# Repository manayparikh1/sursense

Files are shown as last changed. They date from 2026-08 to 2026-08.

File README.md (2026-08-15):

# SurSense

OK so I have been planning this out for years and finally its happening. A palm-sized puck that listens to you play, works out what scale you're in, and drones
along with you playing.

Point it at an instrument and with its mic it names the tonic and the scale in both Western and Indian
notation, like "C# Kafi / Dorian", then plays a tanpura drone tuned to that tonic. It's
also a chromatic tuner and a metronome that knows taal cycles like teental, with a silent
haptic mode so you can use it in an ensemble.

Every tuner tells you one note. BUT almost nothing tells you what key the whole piece is in,
and nothing I've found does it with sargam and a drone attached. So I solved that...

## Status

The detection algorithm is written and tested by me so thats done. The hardware is designed but not built yet because funding is still needed,
so right now this repo is the design plus the software that will run on it.

The self-test scores 24 out of 24 on tonic detection so it works obviously. It generates twelve synthesized
scales per mode, one for each tonic, runs them through the pipeline AND checks the answer in the same time.

## Test it

To test it all you gotta run is this:

cd sur && clang++ -std=c++17 -O2 -Wall -Wextra -o selftest sur.cpp selftest.cpp && ./selftest

THIS WILL ONLY TAKE A FEW SECONDS TRUST LOL. No hardware, no libraries, no build system. Compiles clean under
-Wall -Wextra.

## How it works

1. FFT the incoming audio and find the peaks, with parabolic interpolation so low notes
   land on the right semitone instead of smearing across two.
2. Fold those peaks into 12 pitch classes, weighted by how close each peak sits to the
   centre of a semitone. Accumulate over a few seconds.
3. Correlate against the Krumhansl-Schmuckler probe-tone profile at all 12 rotations to
   find the tonic.
4. Break major/minor ties with a second accumulator that decays more slowly. Whichever
   pitch class stays lit longest is the tonic.
5. Match what's left against the scale candidates.
6. Hold the answer with a locking state machine. Lock easily, unlock reluctantly, so the
   display isn't flickering between two guesses.

Step 4 is the bit I didn't get from a paper. C major and A minor use identical notes, so
correlation on its own can't tell them apart. What separates them is which note is being
*sustained* rather than just present which I learned after a good time of research.

THIS IS HOW I TESTED:

I wanted to check that actually mattered, so I measured it. The self-test holds the tonic
for 0.6s and everything else for 0.3s, and that difference is exactly what the sustain bias
reads. As written it scores 24/24, and turning the bias off only drops it to 23/24, because
the timing cue is still there in other ways. Equalise every note to 0.3s and it falls to
21/24 with the bias on, and 14/24 with it off. So the bias is doing real work, but it's a
seven-point difference, not the difference between working and not working. 

## What it can't do

The self-test is synthetic and I wrote both the detector and the grader, so it proves my
implementation matches my intent. It doesn't prove the thing survives a real room.

Short phrases are undecidable no matter how good the code is. Five notes can't tell Dorian
from natural minor if the note that distinguishes them never got played.

Percussion dumps energy across every bin and will drag accuracy down so yeah.

And nothing has run on hardware yet.

BUT WE WILL FIX MOSTLY ALLLLL OF THAT once the hardware arrives because I am going full-in in this project.

## Hardware

70mm puck, 22mm tall. The knurled metal bezel is the rotary encoder, so the whole ring
turns and you can set tempo by feel without looking down while you're holding an
instrument. It's the same idea as the dial on my AC unit at home.

BOM.csv is also in a sheet which was actually the original one before I made the one in the repo:
https://docs.google.com/spreadsheets/d/1nKPMvtGOhtMLgeP8bByzdkwNMy8-5KtI2vqGwreh8vg/edit?usp=sharing

Total is approx $162.75 USD across ten items, converted from Amazon.ca listings but those prices can prolly flunctuate from times because it already happened to me once which was hectic.

One ESP32-S3, not three. The build only ever needed one processor. Some of the parts only
sell in multipacks, which is why a few line items cost more than a single unit would but it will try to be used because I may need EXTRA pins because of a future plan I have.

### Pin map

One ESP32-S3-WROOM-1-N8R2, 20 GPIO out of 44. Both I2S peripherals are in use, which is the
whole reason for the S3 over an S2 or a classic ESP32: the mic has to capture while the amp
drives the drone. Strapping pins 0, 3, 45 and 46 are left alone.

SD on the amplifier runs off a GPIO instead of being hard-wired, so the amp can be muted
while detection is running. That's the main thing stopping the device from hearing its own
drone and locking onto it.

VBAT sense needs a divider. A full cell sits at 4.2V and the ADC tops out at 3.3V, so GPIO1
can't go straight to the battery. Two 100k resistors and a 100nF cap.

## Design

### Power and signal

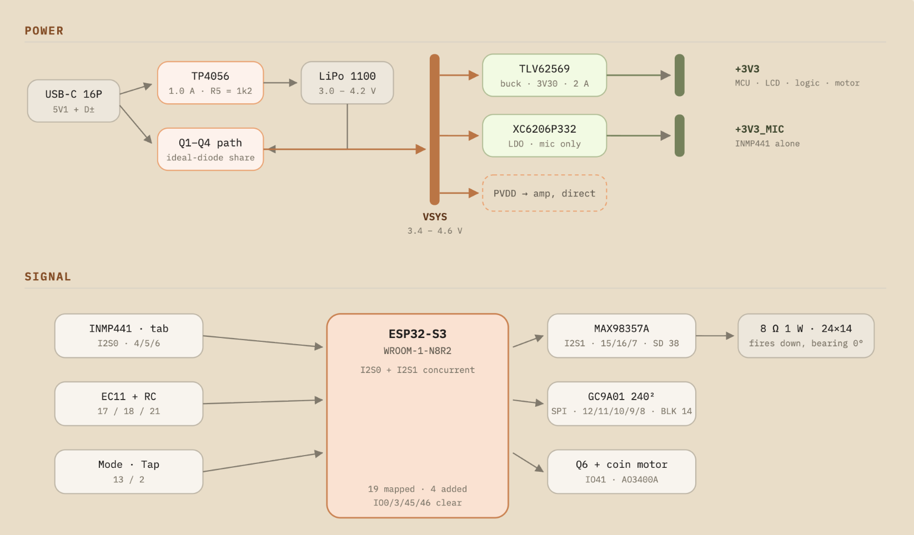
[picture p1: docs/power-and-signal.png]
Power and signal


### PCB placement

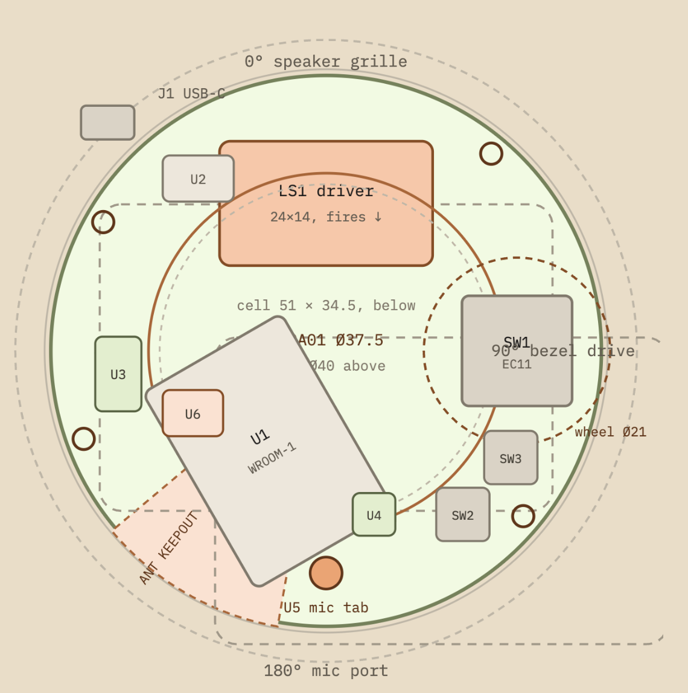
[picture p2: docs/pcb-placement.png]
PCB placement


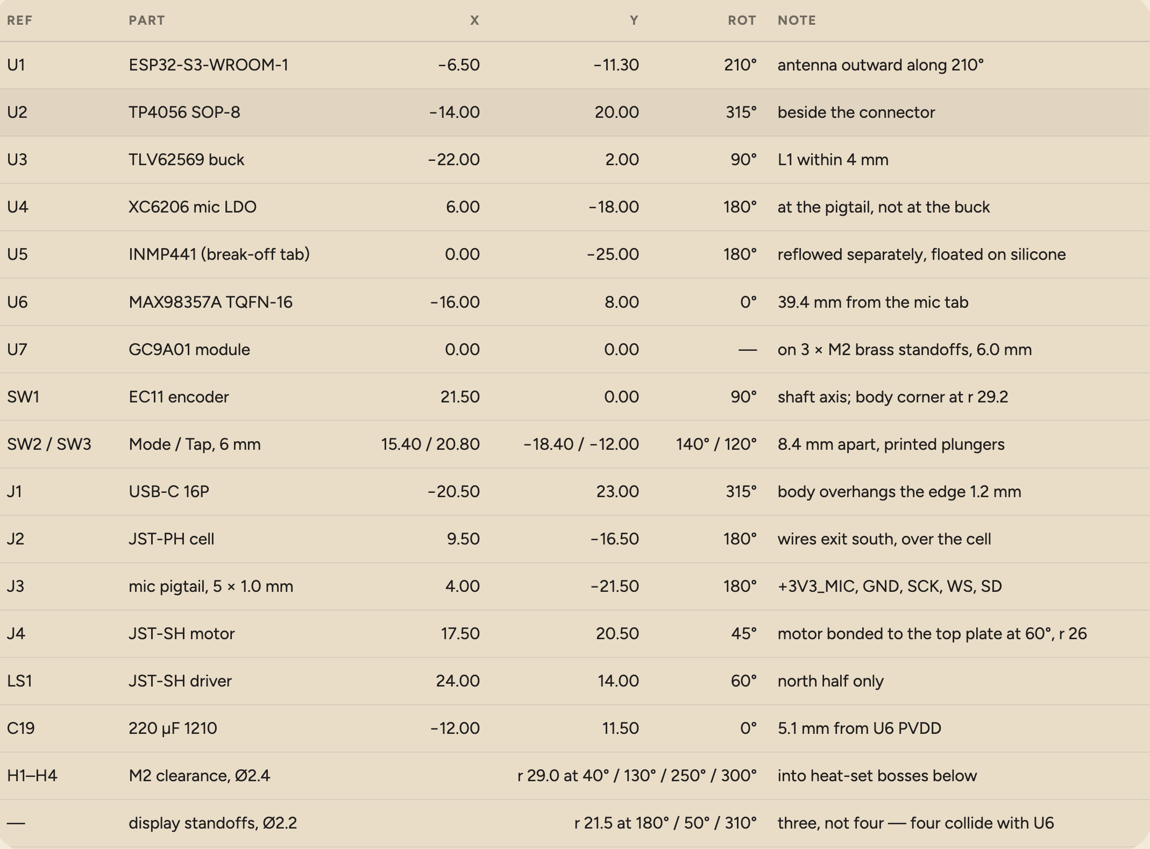
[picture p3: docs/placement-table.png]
Placement table


### Enclosure

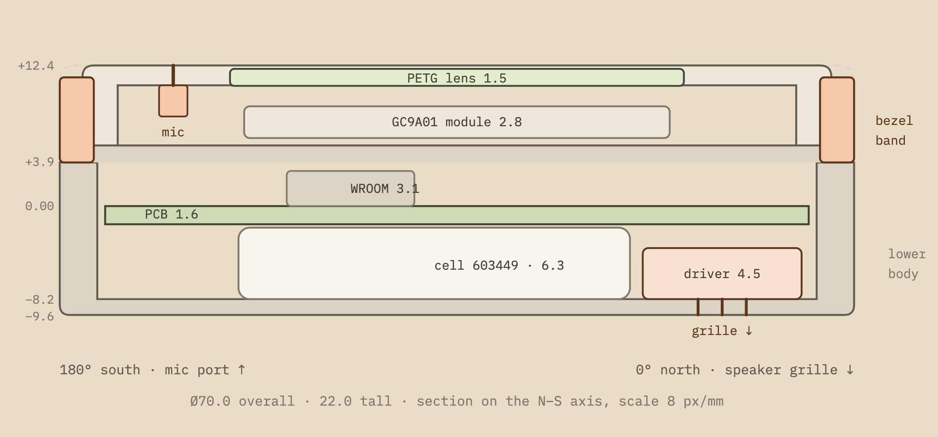
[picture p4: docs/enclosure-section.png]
Enclosure section


### Bezel coupling

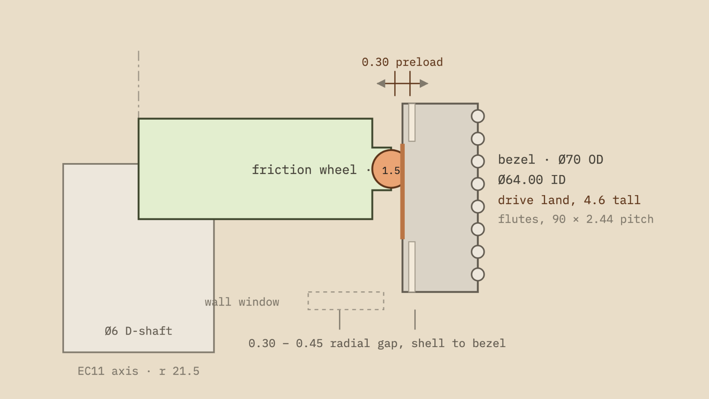
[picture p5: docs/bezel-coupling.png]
Bezel coupling


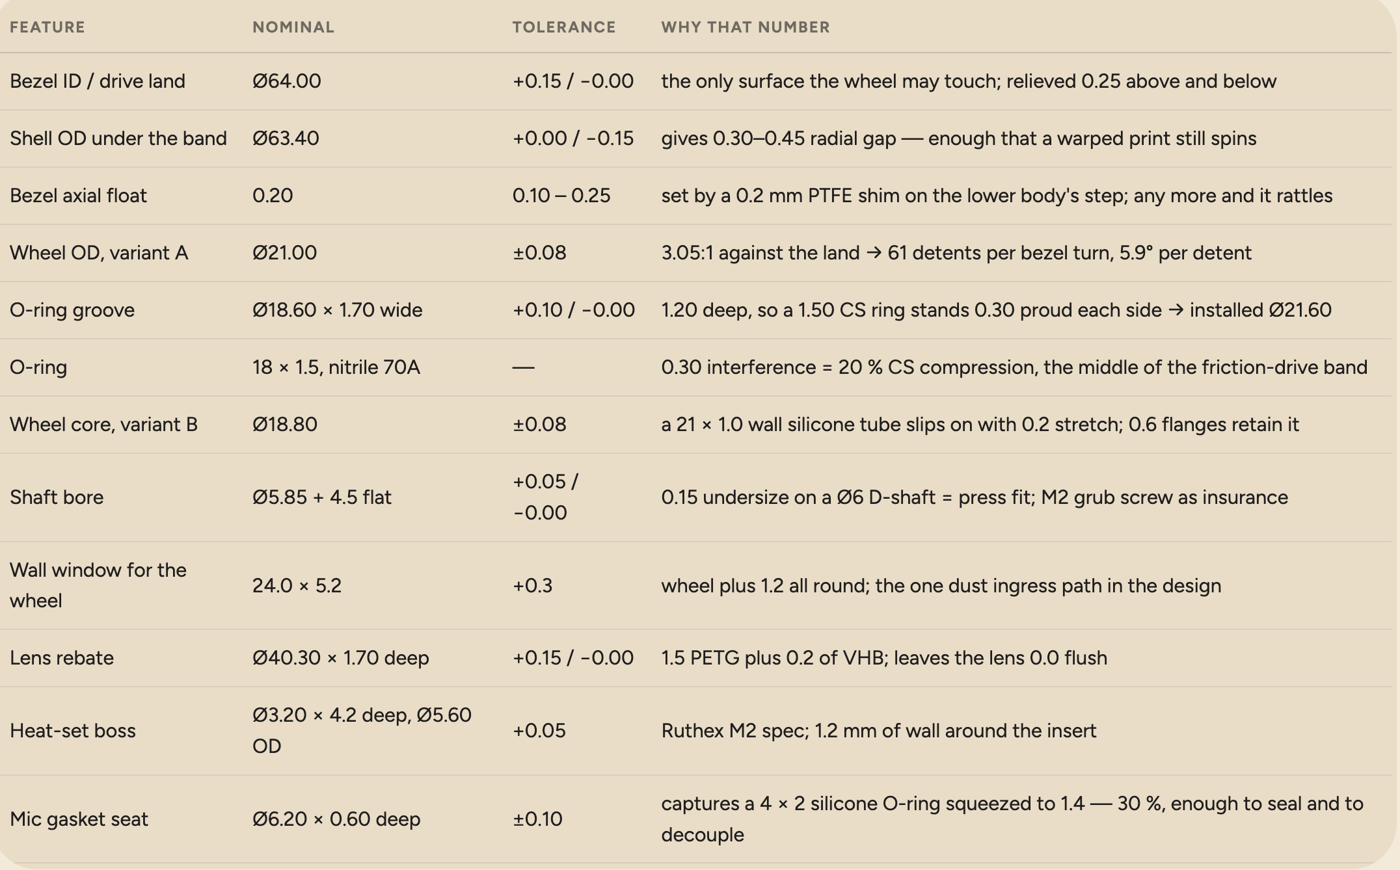
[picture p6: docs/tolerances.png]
Tolerances


## What I think will go wrong

Feedback. The mic and the speaker live in the same shell. If the drone plays while
detection is running the device can hear itself and lock onto its own output, which looks
like it's working perfectly and is actually a loop. Mode exclusivity plus notching out the
drone's own pitches should handle it.

The bezel. Driving an EC11 from a printed knurled ring is the part most likely to feel
rough in v1. I'm budgeting three revisions and printing two different couplings to compare.

The first PCB. Even odds it needs a respin, which is why it gets ordered the day the
breadboard version works rather than before.

**But lets hope for the best**

## Files

BOM.csv is the parts list. sur/ has the detector and its self-test. docs/ has the design
drawings.

I really think this would help a lot of musicians and I'd love to actually build it and look honestly I play a bunch of instruments such as violin, flute, bansuri, harmonium, harmonica, ukulele, and EVEN the tenor sax. And what I have learned is that when playing in a band or something we need to know what scale everyone is playing in ... A FIXED scale which could change sometimes. So overall I hope you guys like this adioss.

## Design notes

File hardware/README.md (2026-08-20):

# SurSense PCB Design

## To build this project:

1. Download KiCad (free, kicad.org)
2. Open `sursense.kicad_pro` in KiCad
3. Create a new schematic and PCB layout using the pin map and placement guide in the main README
4. Export Gerbers to `../production/gerbers/`

## Pin assignments

All pins are documented in the main README under "Pin map".

## Board specs

- Round 2-layer board, 70mm diameter, 1.6mm thick
- Placement coordinates from `docs/placement-table.png`
- Power tree from `docs/power-and-signal.png`

## Design notes

- Mic port at 180°, speaker at 0° (opposite sides)
- EC11 encoder friction coupling at 90°
- WROOM-1 antenna clearance at 210°
- Ground pour under I2S traces
- Class-D amp isolated from MCU power rail

Send Gerbers to JLCPCB or similar 2-layer fab.

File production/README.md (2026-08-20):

# Production files

Everything needed to build one SurSense.

## STEP/

Three printed parts, generated by `cad/enclosure.py`. STEP is the editable
source, STL is ready to slice.

- `lower_shell` — battery bay, speaker grille, USB-C cutout, four M2 bosses
- `upper_shell` — display rebate, mic port and gasket seat, bezel drive window
- `bezel` — the knurled ring that turns the encoder

Print in PLA or PETG, 0.4mm nozzle, 0.2mm layers. The bezel wants to be printed
flat so the flutes come out crisp.

Regenerate with:

    pip install cadquery
    python3 cad/enclosure.py

## gerbers/

Not generated yet. Comes from the KiCad board in `hardware/` once the layout is
routed: File, Fabrication Outputs, Gerbers.

## firmware/

Build from `firmware/` with PlatformIO:

    cd firmware && pio run

The binary lands in `firmware/.pio/build/sursense/firmware.bin`. Flash with
`pio run -t upload`.

## Assembly

1. Solder the board, positions in `docs/placement-table.png`
2. Heat-set four M2 inserts into the lower shell bosses
3. Bond the PETG lens into the upper shell rebate
4. Fit the mic gasket, 4x2 silicone O-ring, into its seat
5. Press the friction wheel onto the EC11 shaft, then fit the bezel
6. Flash over USB-C, then close the shells with four M2x6 screws

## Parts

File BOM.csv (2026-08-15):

Part | Link | Note | Estimate $ | Quantity
ESP32 | https://www.amazon.ca/dp/B0DFTKFWT2 | Main processor. Runs the pitch-detection DSP on one core and the display on the other, with PSRAM for the audio buffer and both I2S peripherals so the mic and amp run at once. | 28.83 | 1
INMP441 I2S mic | https://www.amazon.ca/dp/B0C1C64R8S | Captures the instrument for scale detection and tuning, with a digital output that avoids any analog front-end. | 15.85 | 1
GC9A01 1.28" round display | https://www.amazon.ca/dp/B0CJ5X6RJN | Shows the tonic, scale and sargam. The round format suits the tuner dial, taal cycle and circle-of-fifths views. | 5.77 | 1
MAX98357A I2S amp | https://www.amazon.ca/dp/B0DPJRLMDJ | Combines the DAC and amplifier in one part so the processor drives the drone and metronome click directly. | 11.53 | 1
EC11 rotary encoder | https://www.amazon.ca/dp/B0C6Q67V97 | Sets the tempo, pitch and mode, coupled to the knurled bezel so the whole ring turns and can be adjusted by feel. | 33.02 | 1
8 ohm 1W 28mm speaker | https://www.amazon.ca/dp/B019JMV0JY | Reproduces the drone and click, sized to fit the 70mm enclosure. | 7.21 | 1
Coin vibration motor | https://www.amazon.ca/dp/B01MTOOQD1 | Pulses the beat so the player feels time instead of hearing it, making the metronome usable in an ensemble or under headphones. | 8.3 | 1
TP4056 USB-C charger | https://www.amazon.ca/dp/B09MJXV784 | Charges the cell over USB-C with over-charge, over-discharge and short-circuit protection. | 9.37 | 1
3.7V 1000mAh LiPo | https://www.amazon.ca/dp/B0CNLPBM2L | Gives about 8 hours of untethered use so the device works on a music stand rather than beside an outlet. | 24.14 | 1
Jumper wires + breadboard | https://www.amazon.ca/dp/B07JKKNDHK | Validate the full circuit and firmware before committing to a PCB, so design errors are caught while they cost nothing. | 18.73 | 1
 |  |  | Total: ~$162.75 USD | Total items: 10

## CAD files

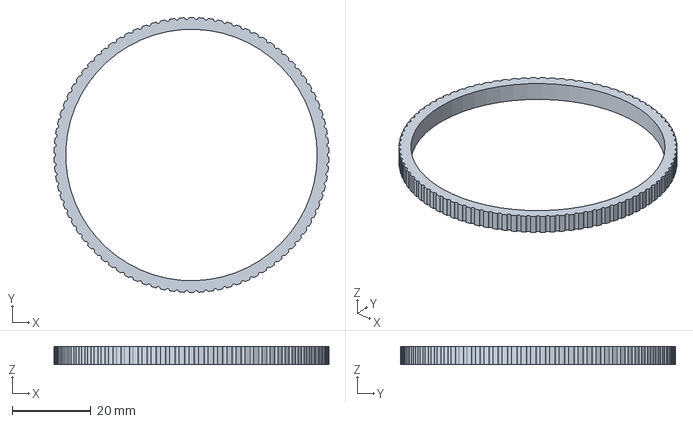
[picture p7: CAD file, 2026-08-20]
production/STEP/bezel.step
70.0 x 70.0 x 4.60 mm

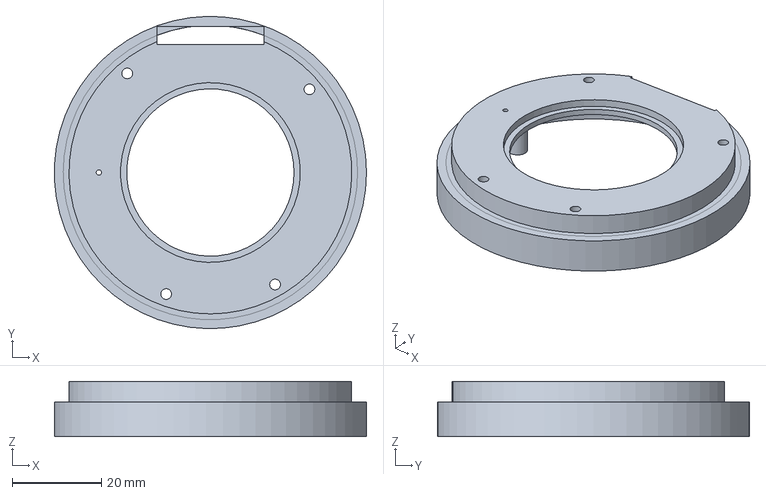
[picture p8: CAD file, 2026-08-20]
production/STEP/upper_shell.step
70.0 x 70.0 x 12.4 mm

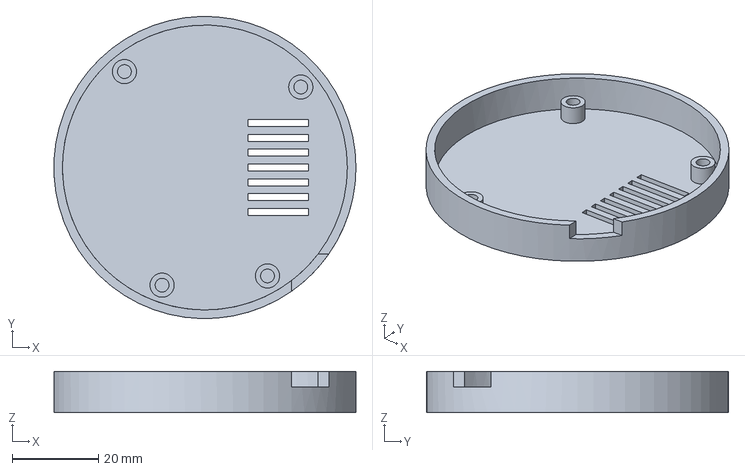
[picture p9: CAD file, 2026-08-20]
production/STEP/lower_shell.step
70.0 x 70.0 x 9.60 mm

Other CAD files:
production/STEP/bezel.stl
production/STEP/lower_shell.stl
production/STEP/upper_shell.stl

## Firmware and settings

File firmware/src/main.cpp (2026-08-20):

// SurSense firmware
//
// Core 0 captures audio on I2S0, runs the FFT and feeds sur::Detector.
// Core 1 renders the round display and reads the encoder and buttons.
// The two talk through one FreeRTOS queue holding the latest Reading.

#include <Arduino.h>
#include <Arduino_GFX_Library.h>
#include <driver/i2s.h>
#include <math.h>

#include "pins.h"
#include "sur.h"

// ------------------------------------------------------------------ audio

constexpr int kSampleRate = 22050;   // enough for the top of the range we chase
constexpr int kFFT = 1024;           // 21.5 Hz per bin
constexpr float kBinHz = (float)kSampleRate / kFFT;

static float g_re[kFFT];
static float g_im[kFFT];
static float g_mag[kFFT / 2];
static float g_window[kFFT];
static int32_t g_raw[kFFT];

static sur::Detector g_detector;
static QueueHandle_t g_readings;

// Radix-2 FFT, in place. Replace with esp-dsp's dsps_fft2r_fc32 if you want
// the assembly-optimised version; this is here so the build has no extra deps.
static void fft(float* re, float* im, int n) {
  for (int i = 1, j = 0; i < n; ++i) {
    int bit = n >> 1;
    for (; j & bit; bit >>= 1) j ^= bit;
    j ^= bit;
    if (i < j) {
      float t = re[i]; re[i] = re[j]; re[j] = t;
      t = im[i]; im[i] = im[j]; im[j] = t;
    }
  }
  for (int len = 2; len <= n; len <<= 1) {
    const float ang = -6.283185307f / len;
    for (int i = 0; i < n; i += len) {
      float cr = 1.0f, ci = 0.0f;
      for (int k = 0; k < len / 2; ++k) {
        const int a = i + k, b = a + len / 2;
        const float tr = re[b] * cr - im[b] * ci;
        const float ti = re[b] * ci + im[b] * cr;
        re[b] = re[a] - tr;  im[b] = im[a] - ti;
        re[a] += tr;         im[a] += ti;
        const float ncr = cr * cosf(ang) - ci * sinf(ang);
        ci = cr * sinf(ang) + ci * cosf(ang);
        cr = ncr;
      }
    }
  }
}

static void mic_begin() {
  i2s_config_t cfg = {};
  cfg.mode = (i2s_mode_t)(I2S_MODE_MASTER | I2S_MODE_RX);
  cfg.sample_rate = kSampleRate;
  cfg.bits_per_sample = I2S_BITS_PER_SAMPLE_32BIT;
  cfg.channel_format = I2S_CHANNEL_FMT_ONLY_LEFT;
  cfg.communication_format = I2S_COMM_FORMAT_STAND_I2S;
  cfg.intr_alloc_flags = ESP_INTR_FLAG_LEVEL1;
  cfg.dma_buf_count = 4;
  cfg.dma_buf_len = 256;
  cfg.use_apll = false;

  i2s_pin_config_t pins = {};
  pins.bck_io_num = PIN_MIC_SCK;
  pins.ws_io_num = PIN_MIC_WS;
  pins.data_in_num = PIN_MIC_SD;
  pins.data_out_num = I2S_PIN_NO_CHANGE;

  i2s_driver_install(I2S_NUM_0, &cfg, 0, nullptr);
  i2s_set_pin(I2S_NUM_0, &pins);
}

static void audio_task(void*) {
  for (int i = 0; i < kFFT; ++i) {
    g_window[i] = 0.5f * (1.0f - cosf(6.283185307f * i / (kFFT - 1)));
  }

  uint32_t last = millis();

  for (;;) {
    size_t got = 0;
    i2s_read(I2S_NUM_0, g_raw, sizeof(g_raw), &got, portMAX_DELAY);
    const int n = got / sizeof(int32_t);
    if (n < kFFT) continue;

    // INMP441 gives 24 bits left justified in a 32 bit slot.
    float rms = 0.0f;
    for (int i = 0; i < kFFT; ++i) {
      const float s = (float)(g_raw[i] >> 8) / 8388608.0f;
      rms += s * s;
      g_re[i] = s * g_window[i];
      g_im[i] = 0.0f;
    }
    rms = sqrtf(rms / kFFT);

    fft(g_re, g_im, kFFT);
    for (int i = 0; i < kFFT / 2; ++i) {
      g_mag[i] = sqrtf(g_re[i] * g_re[i] + g_im[i] * g_im[i]);
    }

    const uint32_t now = millis();
    const float dt = (now - last) / 1000.0f;
    last = now;

    sur::Reading r = g_detector.update(g_mag, kFFT / 2, kBinHz, dt, rms);
    xQueueOverwrite(g_readings, &r);
  }
}

// ---------------------------------------------------------------- display

static Arduino_DataBus* bus = new Arduino_ESP32SPI(
    PIN_TFT_DC, PIN_TFT_CS, PIN_TFT_SCL, PIN_TFT_SDA, GFX_NOT_DEFINED);
static Arduino_GFX* gfx = new Arduino_GC9A01(bus, PIN_TFT_RST, 0, true);

static void draw(const sur::Reading& r) {
  gfx->fillScreen(BLACK);

  gfx->setTextColor(r.locked ? GREEN : DARKGREY);
  gfx->setTextSize(2);
  gfx->setCursor(84, 40);
  gfx->print(r.locked ? "LOCKED" : "LISTEN");

  if (r.tonic < 0) return;

  gfx->setTextColor(WHITE);
  gfx->setTextSize(6);
  gfx->setCursor(80, 90);
  gfx->print(sur::kNoteNames[r.tonic]);

  if (r.scale) {
    gfx->setTextSize(2);
    gfx->setTextColor(CYAN);
    gfx->setCursor(50, 155);
    gfx->print(r.scale->thaat);
    gfx->print(" . ");
    gfx->print(r.scale->western);
  }
}

// -------------------------------------------------------------------- app

void setup() {
  Serial.begin(115200);

  pinMode(PIN_AMP_SD, OUTPUT);
  digitalWrite(PIN_AMP_SD, LOW);   // amp muted while we listen
  pinMode(PIN_MOTOR, OUTPUT);
  digitalWrite(PIN_MOTOR, LOW);
  pinMode(PIN_BTN_MODE, INPUT_PULLUP);
  pinMode(PIN_BTN_TAP, INPUT_PULLUP);
  pinMode(PIN_ENC_A, INPUT_PULLUP);
  pinMode(PIN_ENC_B, INPUT_PULLUP);
  pinMode(PIN_ENC_SW, INPUT_PULLUP);

  pinMode(PIN_TFT_BLK, OUTPUT);
  digitalWrite(PIN_TFT_BLK, HIGH);
  gfx->begin();
  gfx->fillScreen(BLACK);

  g_readings = xQueueCreate(1, sizeof(sur::Reading));
  mic_begin();
  g_detector.reset();

  // audio is hard real time, pin it to core 0 and leave core 1 for the UI
  xTaskCreatePinnedToCore(audio_task, "audio", 8192, nullptr, 5, nullptr, 0);
}

void loop() {
  sur::Reading r;
  if (xQueueReceive(g_readings, &r, pdMS_TO_TICKS(100)) == pdTRUE) {
    draw(r);
  }
}

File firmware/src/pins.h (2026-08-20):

#pragma once

// SurSense pin map. One ESP32-S3-WROOM-1, 20 GPIO of 44.
// Strapping pins 0, 3, 45 and 46 are left clear.
// This file is the single source of truth; the README table mirrors it.

// INMP441 microphone, I2S peripheral 0. L/R is tied to GND for the left slot.
constexpr int PIN_MIC_SCK = 4;
constexpr int PIN_MIC_WS  = 5;
constexpr int PIN_MIC_SD  = 6;

// MAX98357A amplifier, I2S peripheral 1.
constexpr int PIN_AMP_DIN  = 7;
constexpr int PIN_AMP_BCLK = 15;
constexpr int PIN_AMP_LRC  = 16;
constexpr int PIN_AMP_SD   = 38;  // shutdown, driven low to mute while detecting

// GC9A01 round display, SPI.
constexpr int PIN_TFT_RST = 8;
constexpr int PIN_TFT_DC  = 9;
constexpr int PIN_TFT_CS  = 10;
constexpr int PIN_TFT_SDA = 11;
constexpr int PIN_TFT_SCL = 12;
constexpr int PIN_TFT_BLK = 14;  // backlight, PWM capable

// EC11 encoder, driven by the knurled bezel.
constexpr int PIN_ENC_A  = 17;
constexpr int PIN_ENC_B  = 18;
constexpr int PIN_ENC_SW = 21;

// Buttons and haptics.
constexpr int PIN_BTN_MODE = 13;
constexpr int PIN_BTN_TAP  = 2;
constexpr int PIN_MOTOR    = 41;  // coin motor through an N-channel MOSFET

// Battery sense. Divider is 2x 100k, so the ADC reads half of VBAT.
constexpr int PIN_VBAT = 1;
constexpr float VBAT_DIVIDER = 2.0f;

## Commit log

2026-08-03 Add web demo and BOM
    [BOM.csv]
2026-08-14 Address grant review: USD BOM, one ESP32, design docs, repo cleanup
    BOM (BOM.csv)
    - Convert all prices to USD at 1 CAD = 0.72 USD. Total $154.26.
    - Verify all ten Amazon.ca links live; replace three that were broken:
    - ESP32 link was an out-of-stock 3-pack, which is why the parts list
    read as three processors. Replaced with an in-stock single board.
    - TP4056 link was out of stock. Replaced.
    - LiPo link pointed at a 5000mAh 115659 cell, not the 1000mAh 803040
    the BOM specified. Replaced with a 1100mAh 603449 (34.5x51x6.3mm,
    JST-PH 2.0) that fits the 70mm x 22mm puck.
    - Correct prices against live listings; several estimates were well off
    (display $24 -> $7.99, encoder 6-pa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
    [BOM.csv]
2026-08-14 Add hardware design documents to the repo
    Six design renders under docs/, replacing the placeholder interconnect
    diagram, which they supersede:
    - power-and-signal: four-rail power tree and the signal block map
    - pcb-placement + placement-table: round 2-layer board, per-part X/Y/rot
    - enclosure-section: Z stack on the N-S axis, closes at 22.00mm
    - bezel-coupling + tolerances: both drive variants, fits and reasoning
    Reconcile the repo against the design:
    - Add MAX98357A SD to the pin map on GPIO38. GPIO-controlled shutdown
    lets the amp mute during detection, which is the main defence against
    the device hearing its own drone.
    - Correct the GPIO count to 20 of 44; it read 19 of 36, and the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
    [BOM.csv]
2026-08-14 Remove HARDWARE.md and FIRMWARE.md
    Move the pin map into the README so the design documents in docs/ still
    have something to reference, and drop the two dangling pointers.
    [BOM.csv]
2026-08-15 Rewrite the README in plain prose
    No bold, no tables, no em-dashes. Pin map moved to a code block and the
    ablation numbers written out as a sentence. Design images unchanged.
2026-08-15 Match BOM.csv to the sheet
    [BOM.csv]
2026-08-20 Add hardware design structure and CAD enclosure generator
    - hardware/ folder with README explaining KiCad workflow
    - production/ folder with documentation for gerbers, STEP, firmware
    - cad/enclosure.py generates 3D STEP files for the case (CadQuery)
    User still needs to:
    1. Create KiCad schematic and PCB in hardware/
    2. Export gerbers to production/gerbers/
    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
2026-08-20 Fix KiCad project file
2026-08-20 Add KiCad schematic
    Nine components wired: ESP32-S3-WROOM-1, MAX98357A, microphone and
    display connectors, EC11, two buttons, battery and USB-C.
    [sursense.kicad_sch]
2026-08-20 Add CAD, firmware and production files
    cad/enclosure.py generates three parts as STEP and STL. Rebuilt the
    upper shell as a revolved profile: the previous version stepped the
    outside in under the bezel band to a smaller radius than the inner
    cavity, which removed the wall entirely and split the part in two.
    All three parts now come out as single solids and stack to 22.00mm.
    firmware/ is a PlatformIO project for the ESP32-S3. I2S0 capture, FFT
    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
    [bezel.step, bezel.stl, lower_shell.step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]
2026-08-20 Fix schematic shorts by replacing wires with net labels
    The wired version collapsed 57 wires into 3 nets. A single vertical
    wire ran down the left pin column of U1 acting as a busbar, so every
    horizontal run terminating on it was welded to the same net, with
    battery + tied to battery -.
    Replaced all wires and junctions with net labels placed on the pins.
    Now 20 nets, largest is GND, and every net matches the README pin map:
    mic on IO4/5/6, amp on IO7/15/16 with shutdown on IO38, display on
    IO8-IO12 and IO14, encoder on IO17/18, buttons on IO13 and IO2.
    Also drop cad/__pycache__ from the repo.
    [sursense.kicad_sch]
